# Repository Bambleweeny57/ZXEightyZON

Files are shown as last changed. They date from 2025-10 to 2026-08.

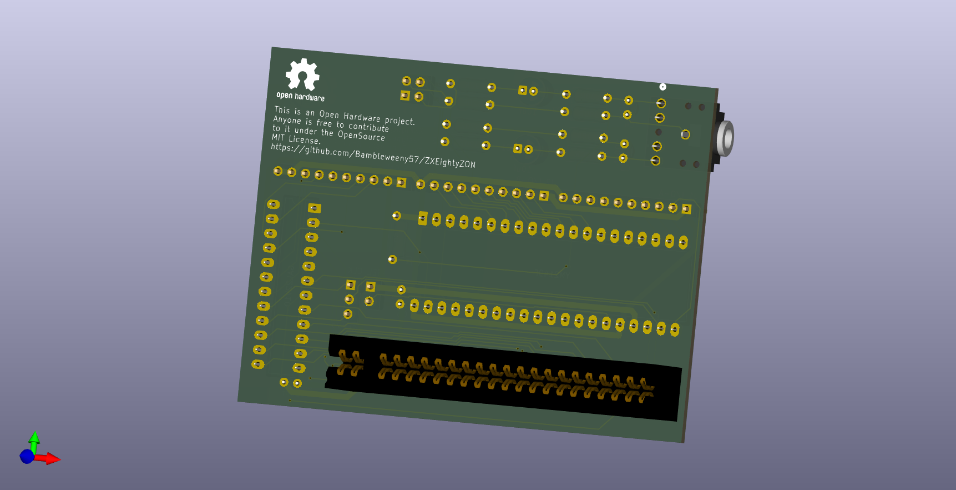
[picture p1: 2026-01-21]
images/zxeightyzon 3D 1.png

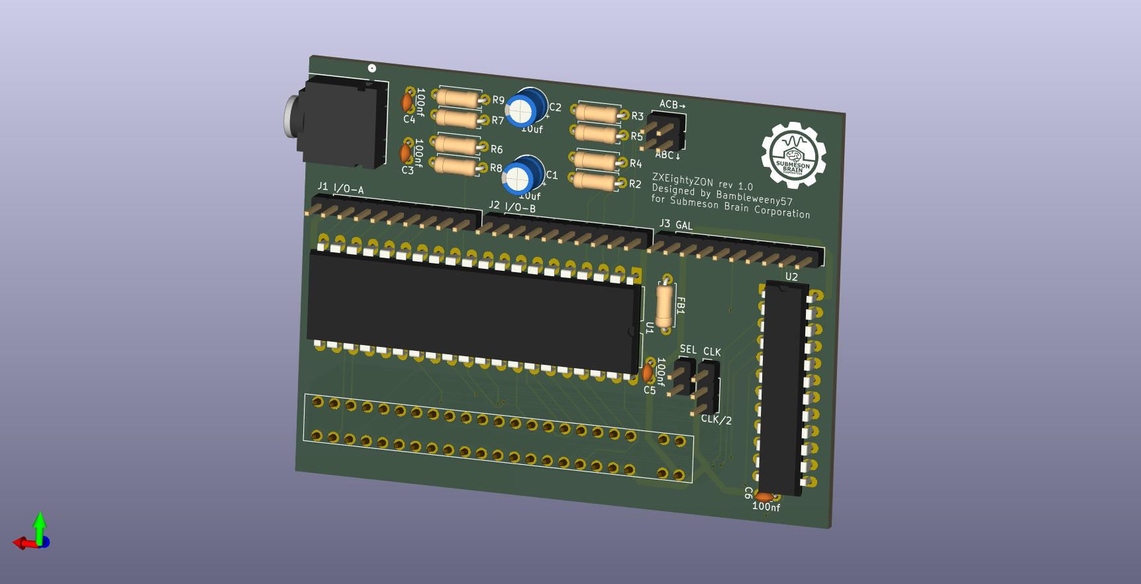
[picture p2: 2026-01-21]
images/zxeightyzon 3D 2.png

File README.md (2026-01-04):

# ZXEightyZON 🎶

**ZXEightyZON** is a new sound interface for the ZX81, built around the **YM2149F** or **AY-3-8910** sound chips. 
Designed as a timing-accurate ZON-compatible sound card, this board offers clean integration with existing ZON-X81 and ZON-X demos and playback routines, while introducing flexible channel mixing options for stereo output.

---

## 🔧 Key Features

- **Sound Chip**: YM2149F or AY-3-8910
- **Address Decoding**:  
  Generic 8-bit address decoding via GAL logic, supporting all 4 known ZON-X register and data address combinations:
  - Latch: `0xDF`, Data: `0x0F` → Modified ZON-X  
  - Latch: `0xCF`, Data: `0x1F` → Original ZON-X  
  - Latch: `0xCF`, Data: `0x0F` → From ZON-X user manual  
  - Latch: `0xDF`, Data: `0x1F` → Additional combination
- **Stereo Output Configuration**:
  - Channel A: Always routed to **Left**
  - Mixed Channel: Selectable via jumper—either **Channel B** or **Channel C**
  - Right Channel: Assigned to the **non-mixed** channel  
    - If **B is mixed**, then **C is Right**  
    - If **C is mixed**, then **B is Right**
- **Noise Channel Nomination**:
  - Jumper-based selection of B or C as the mixed/noise channel
  - Supports regional playback preferences:
    - Western demos typically mix **Channel B**
    - Eastern demos often mix **Channel C**
- **Master Clock Selection**:
  - Jumper-based selection for either bus clock or divided-by-2 clock
  - `CLK_OUT`: Buffered ZX81 bus clock (YM2149 SEL = GND)
  - `CLK_DIV2`: Internally divided clock (YM2149 SEL = !GND or AY-3-8910)
- **PSG Clock Divider Control**:
  - Jumper-based selection for whether PSG divides master clock (YM2149) or receives pre-divided clock
  - **Closed**: Connect YM2149 SEL to GND (PSG divides clock - use with YM2149 only)
  - **Open**: Disconnect SEL from GND (PSG uses divided clock - use with YM2149 or AY-3-8910)

---

## 📌 Pin Assignments (GAL22V10)

| Pin | Signal | Description |
|-----|---|---|
| 01  | CLK_IN | Input clock |
| 02  | A0 | Address bit 0 |
| 03  | A1 | Address bit 1 |
| 04  | A2 | Address bit 2 |
| 05  | A3 | Address bit 3 |
| 06  | A4 | Address bit 4 |
| 07  | A5 | Address bit 5 |
| 08  | A6 | Address bit 6 |
| 09  | A7 | Address bit 7 |
| 10  | !WR_N | Active-low write signal |
| 11  | !IORQ_N | Active-low I/O request |
| 12  | GND | Ground |
| 13  | !RD_N | Active-low read signal |
| 14  | BDIR | PSG control: data direction |
| 15  | BC1 | PSG control: register/data select |
| 16  | CLK_DIV2 | Divided clock output (toggle logic)  |
| 17  | CLK_OUT | Clock Buffered passthrough |
| 18  | NC | Not connected routed to header |
| 19  | NC | Not connected routed to header |
| 20  | NC | Not connected routed to header |
| 21  | NC | Not connected routed to header |
| 22  | NC | Not connected routed to header |
| 23  | NC | Not connected routed to header |
| 24  | VCC | Power |

---

### 🧮 ZXEightyZON Truth Table – ZON-X Address Variants vs PSG Control Signals

This table maps decoded ZON-X addresses and I/O control signals to PSG control outputs. 
Each variant is listed explicitly to reflect all known ZON-X mappings.

| Variant | /IORQ | /WR  | Address | Operation | BDIR | BC1 |
|---|:-----:|:----:|:---:|:---|:----:|:---:|
| Modified ZON-X | Low | Low  | 0xDF | Latch | 1 | 1 |
| Modified ZON-X | Low | Low  | 0x0F | Data Write | 1 | 0 |
| Original ZON-X | Low | Low  | 0xCF | Latch | 1 | 1 |
| Original ZON-X | Low | Low  | 0x1F | Data Write | 1 | 0 |
| Manual Variant | Low | Low  | 0xCF | Latch | 1 | 1 |
| Manual Variant | Low | Low  | 0x0F | Data Write | 1 | 0 |
| Additional Combination | Low | Low  | 0xDF | Latch | 1 | 1 |
| Additional Combination | Low | Low  | 0x1F | Data Write | 1 | 0 |
| — | Any | Any  | — | No Operation  | 0 | 0 |

**Notes:**
- `BDIR` and `BC1` follow PSG truth table conventions for register and data access.
- Address variants are duplicated intentionally to reflect ZON-X lineage and contributor clarity.
- This logic ensures compatibility with Sinclair-era demos and hardware, while supporting AY-ZONIC extensions.

 **Note on `RD` Signal Decoding:**  
> The `RD` line is actively decoded in ZXEightyZON’s GAL logic for completeness and future compatibility. While no current ZON-X compatible software or demos utilize `RD`, its inclusion ensures accurate bus semantics and allows for potential future expansions (e.g., memory-mapped reads or refined timing control). Builders can treat it as provisioned but dormant — present in logic, unused in practice.

---

## 🎚️ AY Channel Assignment Jumper Block

This 2×2 jumper block allows manual swapping of **AY channels B and C** between:

- **CH_B** → Mixed (Left + Right)
- **CH_C** → Right-only

**CH_A is always fixed to Left-only.**

---

### 📐 Pinout Grid

```
╭────────────┬────────────╮
│ [1] B_OUT  │ [2] CH_C   │
├────────────┼────────────┤
│ [3] CH_B   │ [4] C_OUT  │
╰────────────┴────────────╯
```

---

### 🔁 Jumper Combinations

- **Vertical jumpers**  
  - B_OUT → CH_B → Mixed (L+R)  
  - C_OUT → CH_C → Right-only  

- **Horizontal jumpers**  
  - B_OUT → CH_C → Right-only  
  - C_OUT → CH_B → Mixed (L+R)  

---

### 🧠 Notes

- CH_A is always Left-only  
- CH_B feeds Left + Right  
- CH_C feeds Right-only

> Vertical jumpers = B mixed, C right (Western demos)
> Horizontal jumpers = C mixed, B right (Eastern demos)

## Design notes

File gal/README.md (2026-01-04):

# ZXEightyZON GAL Logic – `zxeightyzon.cpl`

**Device:** GAL22V10  
**Revision:** 1.0  
**Designer:** Bambleweeny57  
**Company:** Submeson Brain Corporation  
**Date:** 04-01-2026

This GAL logic handles address decoding and control signal generation for the ZXEightyZON sound interface. 
It supports multiple ZON-X variants and provides clock division and PSG interfacing via BC1 and BDIR. 
All address combinations are genericaly decoded.

---

## 📌 Pin Assignments (GAL22V10)

| Pin | Signal | Description |
|-----|---|---|
| 01  | CLK_IN | Input clock |
| 02  | A0 | Address bit 0 |
| 03  | A1 | Address bit 1 |
| 04  | A2 | Address bit 2 |
| 05  | A3 | Address bit 3 |
| 06  | A4 | Address bit 4 |
| 07  | A5 | Address bit 5 |
| 08  | A6 | Address bit 6 |
| 09  | A7 | Address bit 7 |
| 10  | !R_N | Active-low write signal |
| 11  | !IORQ_N | Active-low I/O request |
| 12  | GND | Ground |
| 13  | !RD_N | Active-low read signal |
| 14  | BDIR | PSG control: data direction |
| 15  | BC1 | PSG control: register/data select |
| 16  | CLK_DIV2 | Divided clock output (toggle logic)  |
| 17  | CLK_OUT | Clock Buffered passthrough |
| 18  | NC | Not connected routed to header |
| 19  | NC | Not connected routed to header |
| 20  | NC | Not connected routed to header |
| 21  | NC | Not connected routed to header |
| 22  | NC | Not connected routed to header |
| 23  | NC | Not connected routed to header |
| 24  | VCC | Power |

---

## 🧩 ZON-X Variant Address Combinations

| Variant Name | Latch Address | Data Address |
|---|---|---|
| Modified ZON-X | 0xDF | 0x0F |
| Original ZON-X | 0xCF | 0x1F |
| Manual Variant | 0xCF | 0x0F |
| Additional Combination  | 0xDF | 0x1F |

---

## 🧠 Logic Overview

### 🔹 Register Select (Latch) and Data Write
```cupl
VALID_IO = IORQ_N & WR_N & A0 & A1 & A2 & A3;
```

### 🔹 Control Signal Logic
```cupl
BDIR = VALID_IO;
BC1  = VALID_IO & A7;
```

### 🔹 Clock Buffered Passthough
```cupl
CLK_OUT = CLK_IN;
```

### 🔹 Clock Divider Logic
```cupl
CLK_DIV2.D = !CLK_DIV2;
```

### 🔹 Output Enables
```cupl
CLK_DIV2.OE = 'b'1;
BDIR.OE = 'b'1;
BC1.OE = 'b'1;
CLK_OUT.OE = 'b'1;
```

**Note on `RD` Signal Decoding:**  
> The `RD` line is not actively decoded in ZXEightyZON’s GAL logic for completeness and future compatibility. 
While no current ZON-X compatible software or demos utilize `RD`, its inclusion ensures accurate bus semantics and allows for potential future expansions (e.g., memory-mapped reads or refined timing control). 
Builders can treat it as provisioned but dormant — present in logic, unused in practice.

---

## 🔧 Build Instructions

1. Edit `gal/src/zxeightyzon.cpl` as needed.
2. Use VS Code task `"Compile ZXEightyZON GAL"` to generate `zxeightyzon.jed`.
3. Use task `"Copy JEDEC to Build"` to move the file to `gal/build/`.
4. Program the GAL22V10 using your programmer e.g.:
   - **T48** with XGPro

---

## 🧪 Testing Notes

- Use logic analyzer or LED rig to verify `BDIR` and `BC1` transitions.
- Confirm clock division on `CLK_DIV2` PIN 16 matches expected toggle rate.
- Confirm clock on `CLK_OUT` PIN 17 matches `CLK_IN` on PIN 1.
- Validate decoding against ZX81 bus activity and PSG response.

---

## 🌀 Integration Context

This GAL logic is part of the **ZXEightyZON** sound interface, enabling compatibility with multiple ZON-X variants and stereo expansion. 
It supports modular decoding and clock handling for PSG control, and is designed for remixable builder workflows.

---

## 🧬 Lore Tag

> “Designed by Bambleweeny57 for Submeson Brain Company, where builder clarity meets retro fidelity.”

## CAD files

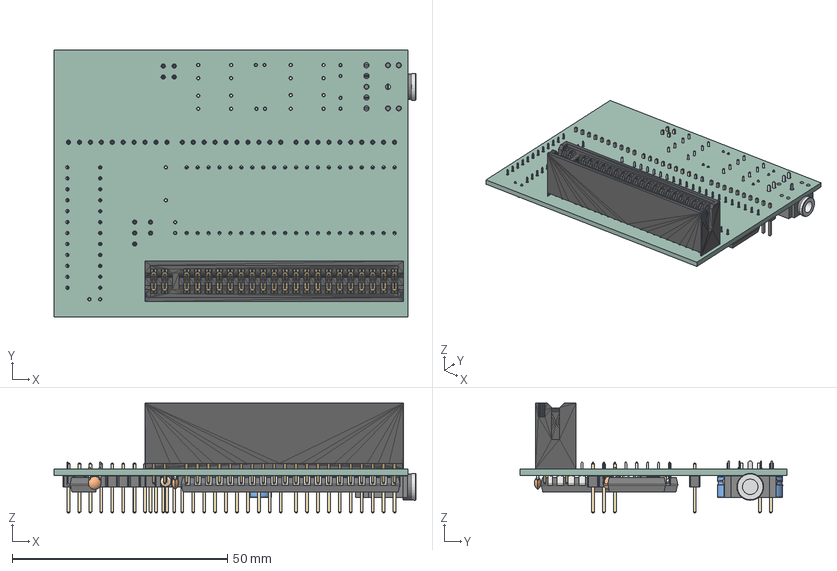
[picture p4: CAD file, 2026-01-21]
images/zxeightyzon.step
84.0 x 62.0 x 25.5 mm
body001 (Solid)
CP_Radial_D5.0mm_P2.00mm x 2
PinHeader_2x02_P2.54mm_Vertical
PinHeader_1x02_P2.54mm_Vertical
PinHeader_1x10_P2.54mm_Vertical x 3
R_Axial_DIN0207_L6.3mm_D2.5mm_P7.62mm_Horizontal x 9
SPC21348
C_Disc_D3.0mm_W1.6mm_P2.50mm x 4
DIP-24_W7.62mm
DIP-40_W15.24mm
PinHeader_1x03_P2.54mm_Vertical
zxeightyzon_PCB

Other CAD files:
images/ZX81_Connector.fcstd
images/ZXEightyZON.FCStd

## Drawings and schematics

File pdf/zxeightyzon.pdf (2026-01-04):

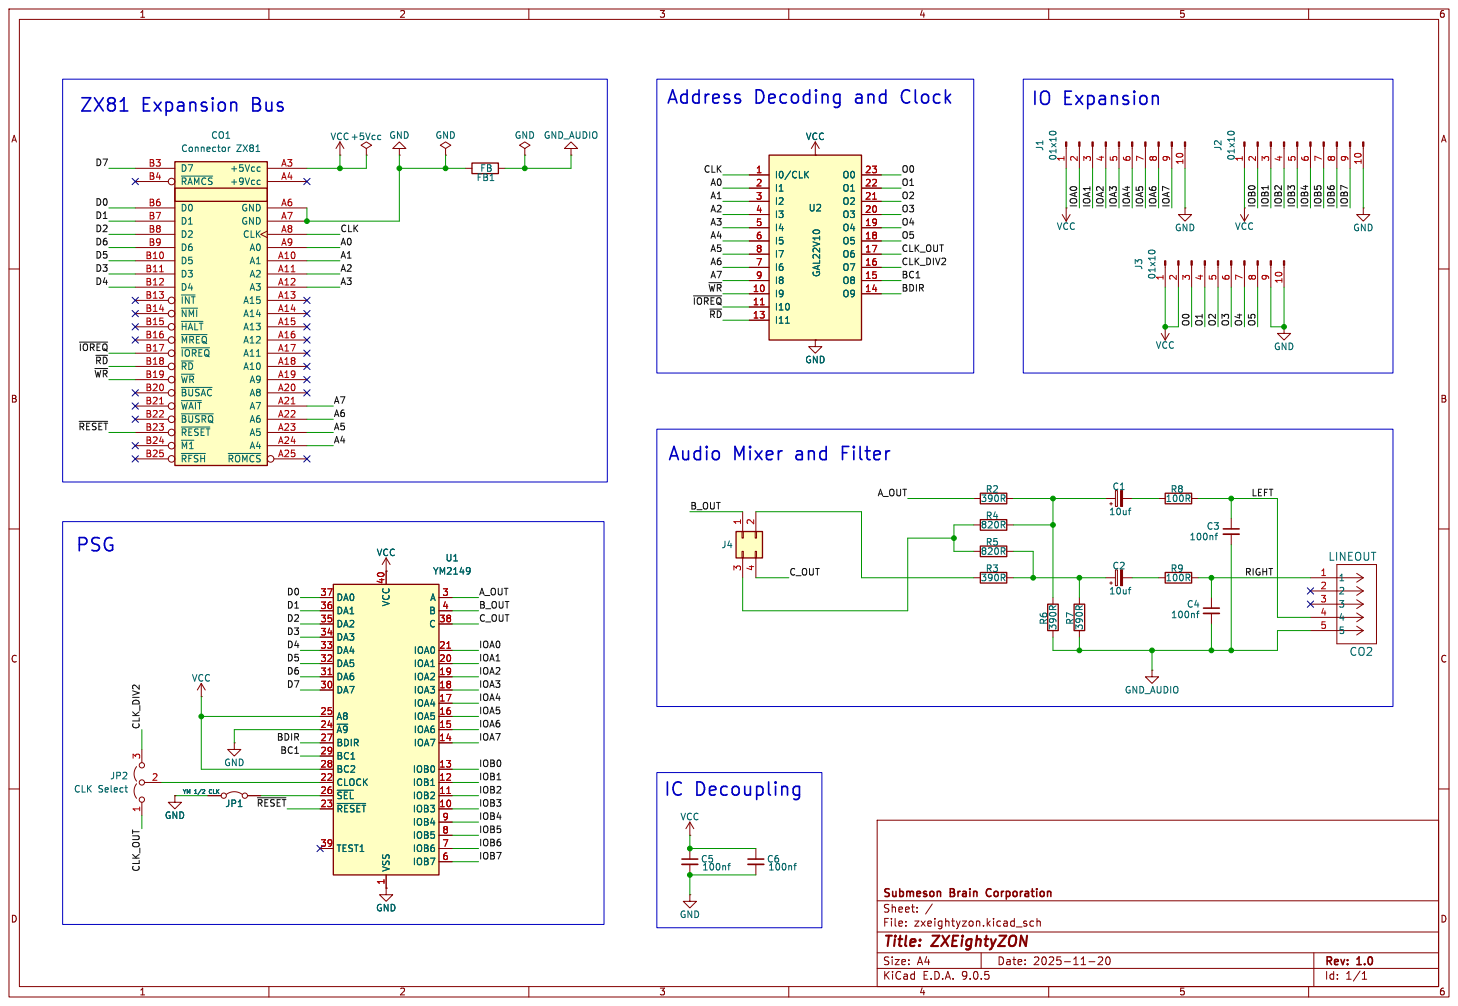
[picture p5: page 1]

Audio Mixer and Filter

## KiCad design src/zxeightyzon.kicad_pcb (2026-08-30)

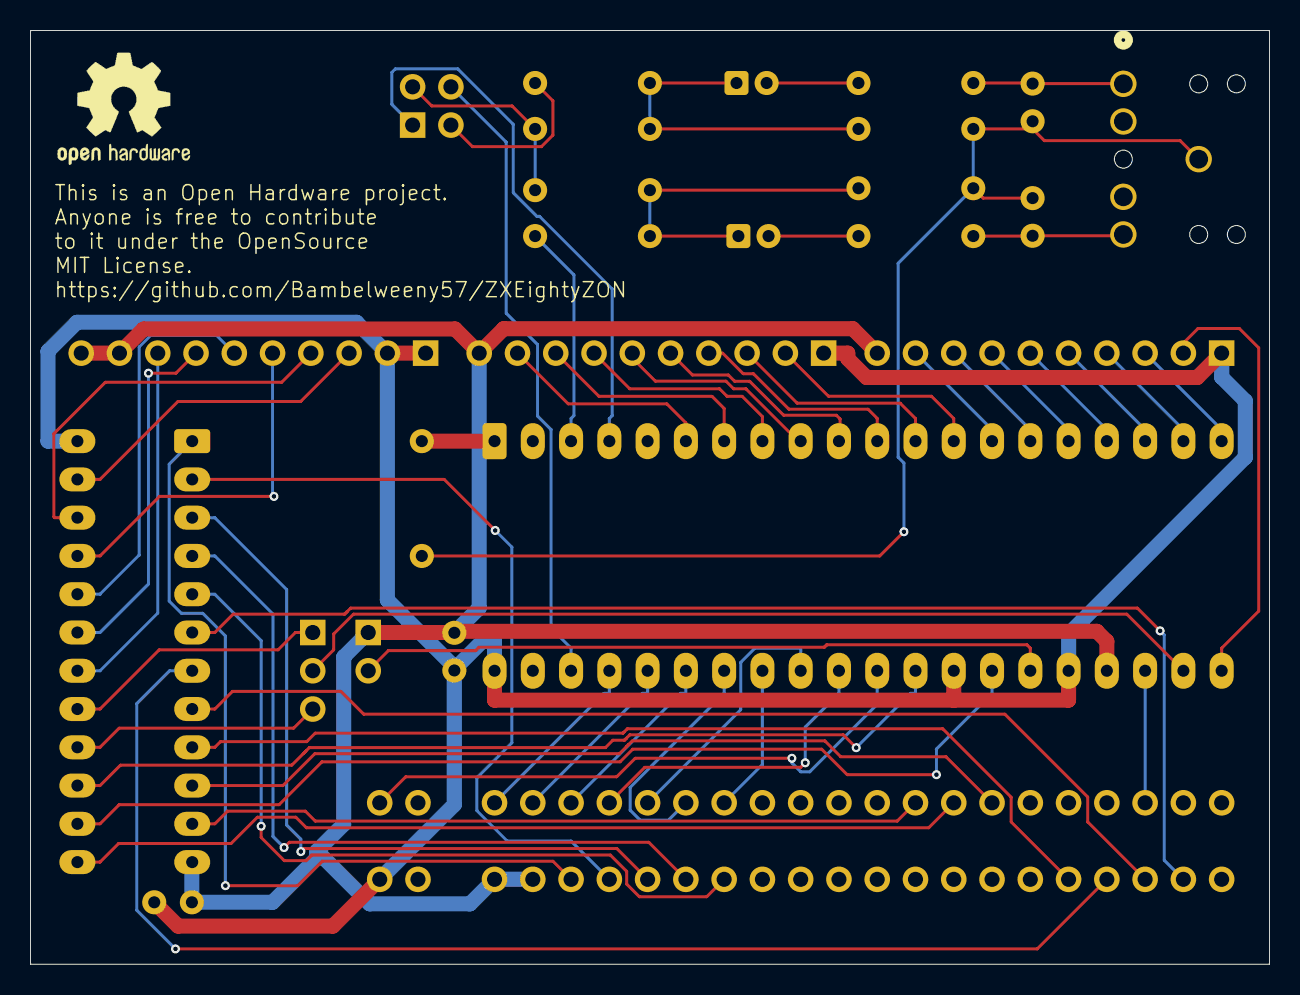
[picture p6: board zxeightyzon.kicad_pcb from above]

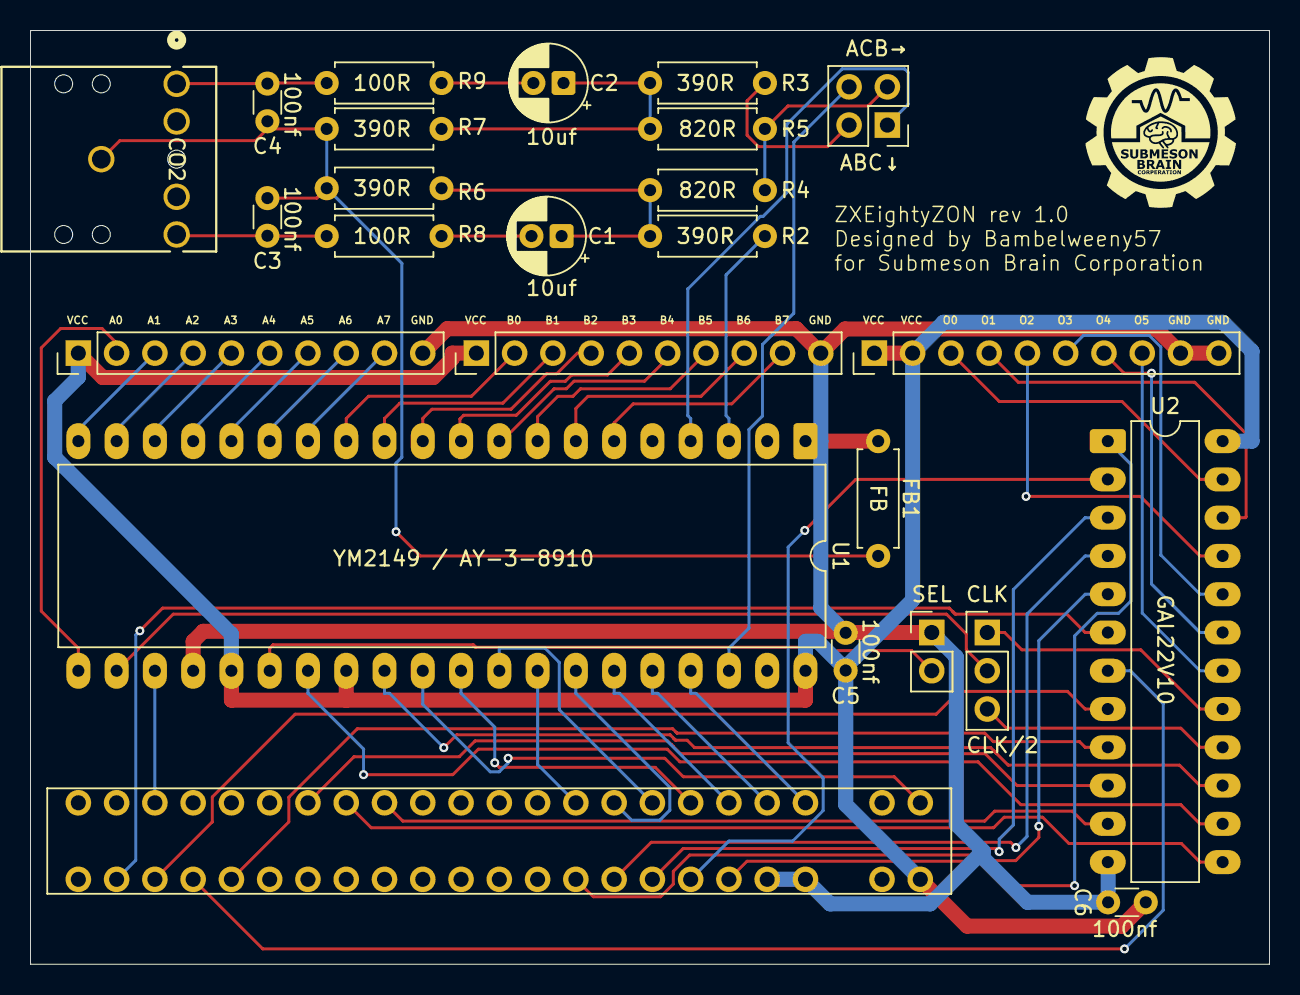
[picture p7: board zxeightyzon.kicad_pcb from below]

Board: 2 copper layers, 82.2 x 62.0 mm, 25 parts (24 on the bottom side), 63 nets.

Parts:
ABC↓: Conn_02x02_Top_Bottom; PinHeader_2x02_P2.54mm_Vertical
C1, C2: 10uf; CP_Radial_D5.0mm_P2.00mm
C3, C4, C5, C6: 100nf; C_Disc_D3.0mm_W1.6mm_P2.50mm
CLK: CLK Select; PinHeader_1x03_P2.54mm_Vertical
CO1: Connector ZX81; ZX81_EdgeConnector
CO2: LINEOUT; CONN5_SPC21348_MTC
FB1: FB; R_Axial_DIN0207_L6.3mm_D2.5mm_P7.62mm_Horizontal
J1 I/O-A, J2 I/O-B, J3 GAL: 01x10; PinHeader_1x10_P2.54mm_Vertical
R2, R3, R6, R7: 390R; R_Axial_DIN0207_L6.3mm_D2.5mm_P7.62mm_Horizontal
R4, R5: 820R; R_Axial_DIN0207_L6.3mm_D2.5mm_P7.62mm_Horizontal
R8, R9: 100R; R_Axial_DIN0207_L6.3mm_D2.5mm_P7.62mm_Horizontal
SEL: YM 1/2 CLK; PinHeader_1x02_P2.54mm_Vertical
U1: YM2149; DIP-40_W15.24mm_LongPads
U2: GAL22V10; DIP-24_W7.62mm_LongPads

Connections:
/A0: CO1.A9 (A0), U2.2 (I1)
/A1: CO1.A10 (A1), U2.3 (I2)
/A2: CO1.A11 (A2), U2.4 (I3)
/A3: CO1.A12 (A3), U2.5 (I4)
/A4: CO1.A24 (A4), U2.6 (I5)
/A5: CO1.A23 (A5), U2.8 (I7)
/A6: CO1.A22 (A6), U2.7 (I6)
/A7: CO1.A21 (A7), U2.9 (I8)
/A_OUT: R2.1, U1.3 (A)
/BC1: U1.29 (BC1), U2.15 (O8)
/BDIR: U1.27 (BDIR), U2.14 (O9)
/B_OUT: ABC↓.1, U1.4 (B)
/CLK: CO1.A8 (CLK), U2.1 (I0/CLK)
/CLK_DIV2: CLK.3 (B), U2.16 (O7)
/CLK_OUT: CLK.1 (A), U2.17 (O6)
/C_OUT: ABC↓.4, U1.38 (C)
/D0: CO1.B6 (D0), U1.37 (DA0)
/D1: CO1.B7 (D1), U1.36 (DA1)
/D2: CO1.B8 (D2), U1.35 (DA2)
/D3: CO1.B11 (D3), U1.34 (DA3)
/D4: CO1.B12 (D4), U1.33 (DA4)
/D5: CO1.B10 (D5), U1.32 (DA5)
/D6: CO1.B9 (D6), U1.31 (DA6)
/D7: CO1.B3 (D7), U1.30 (DA7)
/IOA0: J1 I/O-A.2, U1.21 (IOA0)
/IOA1: J1 I/O-A.3, U1.20 (IOA1)
/IOA2: J1 I/O-A.4, U1.19 (IOA2)
/IOA3: J1 I/O-A.5, U1.18 (IOA3)
/IOA4: J1 I/O-A.6, U1.17 (IOA4)
/IOA5: J1 I/O-A.7, U1.16 (IOA5)
/IOA6: J1 I/O-A.8, U1.15 (IOA6)
/IOA7: J1 I/O-A.9, U1.14 (IOA7)
/IOB0: J2 I/O-B.2, U1.13 (IOB0)
/IOB1: J2 I/O-B.3, U1.12 (IOB1)
/IOB2: J2 I/O-B.4, U1.11 (IOB2)
/IOB3: J2 I/O-B.5, U1.10 (IOB3)
/IOB4: J2 I/O-B.6, U1.9 (IOB4)
/IOB5: J2 I/O-B.7, U1.8 (IOB5)
/IOB6: J2 I/O-B.8, U1.7 (IOB6)
/IOB7: J2 I/O-B.9, U1.6 (IOB7)
/LEFT: C3.1, CO2.4, R8.2
/O0: J3 GAL.3, U2.23 (O0)
/O1: J3 GAL.4, U2.22 (O1)
/O2: J3 GAL.5, U2.21 (O2)
/O3: J3 GAL.6, U2.20 (O3)
/O4: J3 GAL.7, U2.19 (O4)
/O5: J3 GAL.8, U2.18 (O5)
/RIGHT: C4.1, CO2.1, R9.2
/~IOREQ: CO1.B17 (~IOREQ), U2.11 (I10)
/~RD: CO1.B18 (~RD), U2.13 (I11)
/~RESET: CO1.B23 (~RESET), U1.23 (~RESET)
/~WR: CO1.B19 (~WR), U2.10 (I9)
GND: C5.2, C6.2, CO1.A6 (GND), CO1.A7 (GND), FB1.1, J1 I/O-A.10, J2 I/O-B.10, J3 GAL.9, J3 GAL.10, SEL.1 (A), U1.1 (VSS), U1.24 (~A9), U2.12 (GND)
GND_AUDIO: C3.2, C4.2, CO2.5, FB1.2, R6.2, R7.2
unnamed: C1.1, R2.2, R4.1, R6.1
unnamed: C1.2, R8.1
unnamed: C2.1, R3.2, R5.1, R7.1
unnamed: C2.2, R9.1
unnamed: ABC↓.2, R3.1
unnamed: ABC↓.3, R4.2, R5.2
unnamed: SEL.2 (B), U1.26 (~SEL)
unnamed: CLK.2 (C), U1.22 (CLOCK)
VCC: C5.1, C6.1, CO1.A3 (+5Vcc), J1 I/O-A.1, J2 I/O-B.1, J3 GAL.1, J3 GAL.2, U1.25 (A8), U1.28 (BC2), U1.40 (VCC), U2.24 (VCC)

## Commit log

2025-10-19 inital schematic commit
    [zxeightyzon.kicad_pcb, zxeightyzon.kicad_sch]
2025-10-26 changed pin assignmant for clocks
2025-10-26 updated pin assignments to put unused ouputs at the top end
2025-10-26 change schematic to 22v10 and added outline base for pCB
    [zxeightyzon.kicad_pcb, zxeightyzon.kicad_sch]
2025-10-26 started schematic
    [zxeightyzon.kicad_sch]
2025-10-26 added logo footprint
    [zxeightyzon.kicad_pcb]
2025-10-31 started PCB layout
    [zxeightyzon.kicad_pcb, zxeightyzon.kicad_sch]
2025-11-20 fab files
    [zxeightyzon-B_Cu.gbr, zxeightyzon-B_Mask.gbr, zxeightyzon-B_Paste.gbr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]
2026-01-04 Updated CUPL for PIN name
2026-01-04 updated the schematic pdf
2026-01-06 Added silkscreen overlays
    [zxeightyzon-B_Cu.gbr, zxeightyzon-B_Mask.gbr, zxeightyzon-B_Paste.gbr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]
2026-01-21 Added Open Hardware Silk Screen
    [zxeightyzon-B_Cu.gbr, zxeightyzon-B_Mask.gbr, zxeightyzon-B_Paste.gbr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]
2026-01-21 Exported STEP Model and added FreeCad project to create an enclosure.
    [ZX81_Connector.fcstd, ZXEightyZON.FCStd, zxeightyzon.step]
2026-01-21 combined edge connector in to one solid in FreeCad project.
    [ZX81_Connector.fcstd, ZXEightyZON.FCStd]
2026-01-21 Added IO Silk Screen Overlay
    [zxeightyzon-B_Cu.gbr, zxeightyzon-B_Mask.gbr, zxeightyzon-B_Paste.gbr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]
2026-01-21 Re rooted IO A
    [zxeightyzon-B_Cu.gbr, zxeightyzon-B_Mask.gbr, zxeightyzon-B_Paste.gbr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]
2026-08-30 kicad 10
    [zxeightyzon-B_Cu.gbr, zxeightyzon-B_Mask.gbr, zxeightyzon-B_Paste.gbr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]
2026-08-30 new gerbers

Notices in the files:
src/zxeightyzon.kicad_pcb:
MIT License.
